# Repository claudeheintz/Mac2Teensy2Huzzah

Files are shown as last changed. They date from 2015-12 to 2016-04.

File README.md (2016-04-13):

# Mac2Teensy2Huzzah
This is a method for using a Teensy 2.0 or Teensy 2.0++ as a serial bridge so that an Adafruit Huzzah can be programmed from the Arduino IDE on Mac OS X 10.11.

First, load the Mac2Teensy2HuzzahSerialBridge sketch onto the Teensy.  Then, unplug the USB cable from the Mac and connect the Teensy and Huzzah as follows:

Connect V+ and Gnd as well as the serial RX/TX pins.  Note that the RX of the Teensy is connected to TX of the Huzzah and vice-versa.

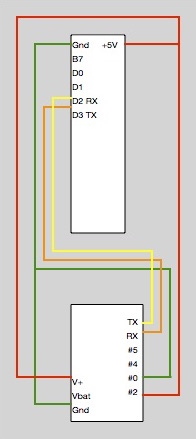
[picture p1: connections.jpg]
Connections


In addition, the Huzzah's GPIO0 pin should be connected to ground and the GPIO2 pin to +V in order to force the Huzzah into programming mode when it is powered on.  Here is the complete setup ready for the USB cable to be plugged into the Mac.

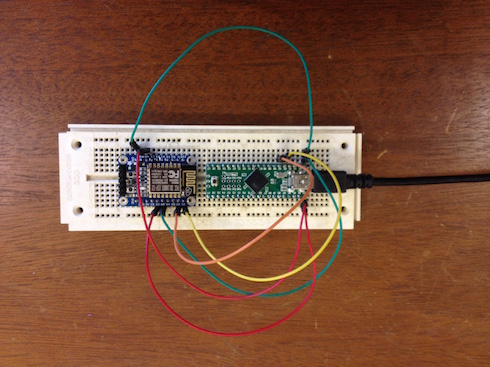
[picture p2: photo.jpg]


Full Step-by-Step:
* Load the Mac2Teensy2Huzzah.ino sketch onto the Teensy.
* Unplug the USB cable and connect the Teensy to the Huzzah as shown.
* Switch to your sketch that you want to load on the Huzzah
* Don't forget to change to Tools->Board: "Adafruit HUZZAH ESP8266".  The Teensy's serial port should still be selected in Tools->Port.
* Plug the USB cable into the Mac and click "Upload".
* After the sketch compiles, you should see the Teensy's LED light up as the program is uploaded to the Huzzah's flash.
* Once the upload is complete, be sure to disconnect GPIO0 from ground and GPIO2 from V+.

Eagle files are included for making a permanent programmer setup with a Teensy 2.0:

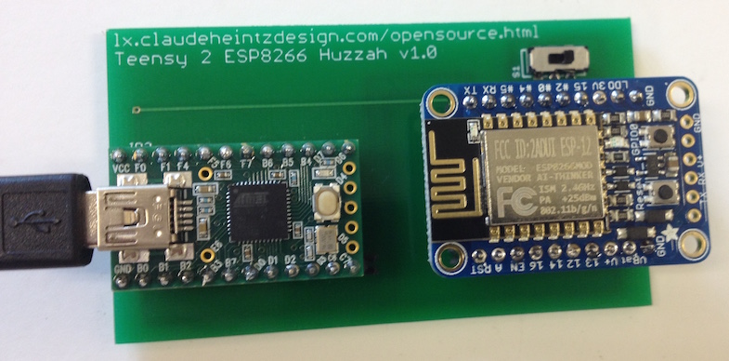
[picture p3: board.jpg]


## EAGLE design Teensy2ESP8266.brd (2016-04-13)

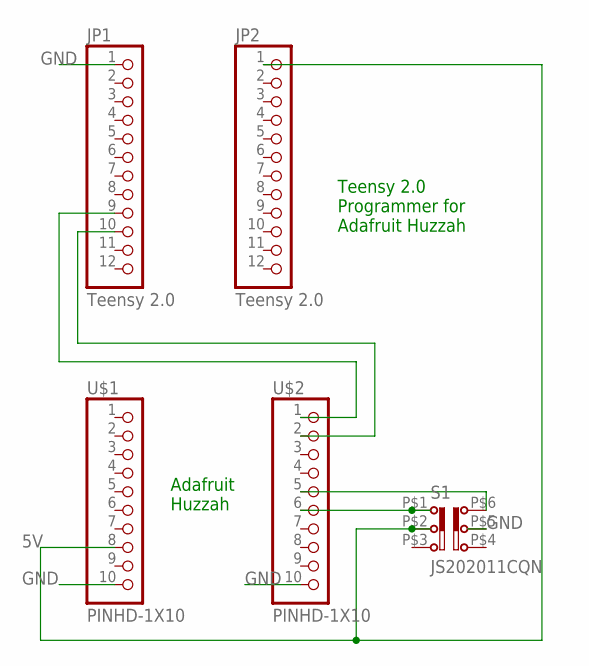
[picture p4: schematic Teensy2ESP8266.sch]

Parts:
JP1, JP2: Teensy 2.0; 1X12
S1: JS202011CQN
U$1, U$2: PINHD-1X10; 1X10-BIG

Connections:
5V: JP2.1, S1.P$2 (2), U$1.8
GND: JP1.1, S1.P$5 (5), U$1.10, U$2.10
unnamed: S1.P$1 (1), U$2.6
unnamed: S1.P$6 (4), U$2.5
RX2: JP1.9, U$2.1
TX2: JP1.10, U$2.2

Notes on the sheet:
Adafruit Huzzah
Teensy 2.0 Programmer for Adafruit Huzzah

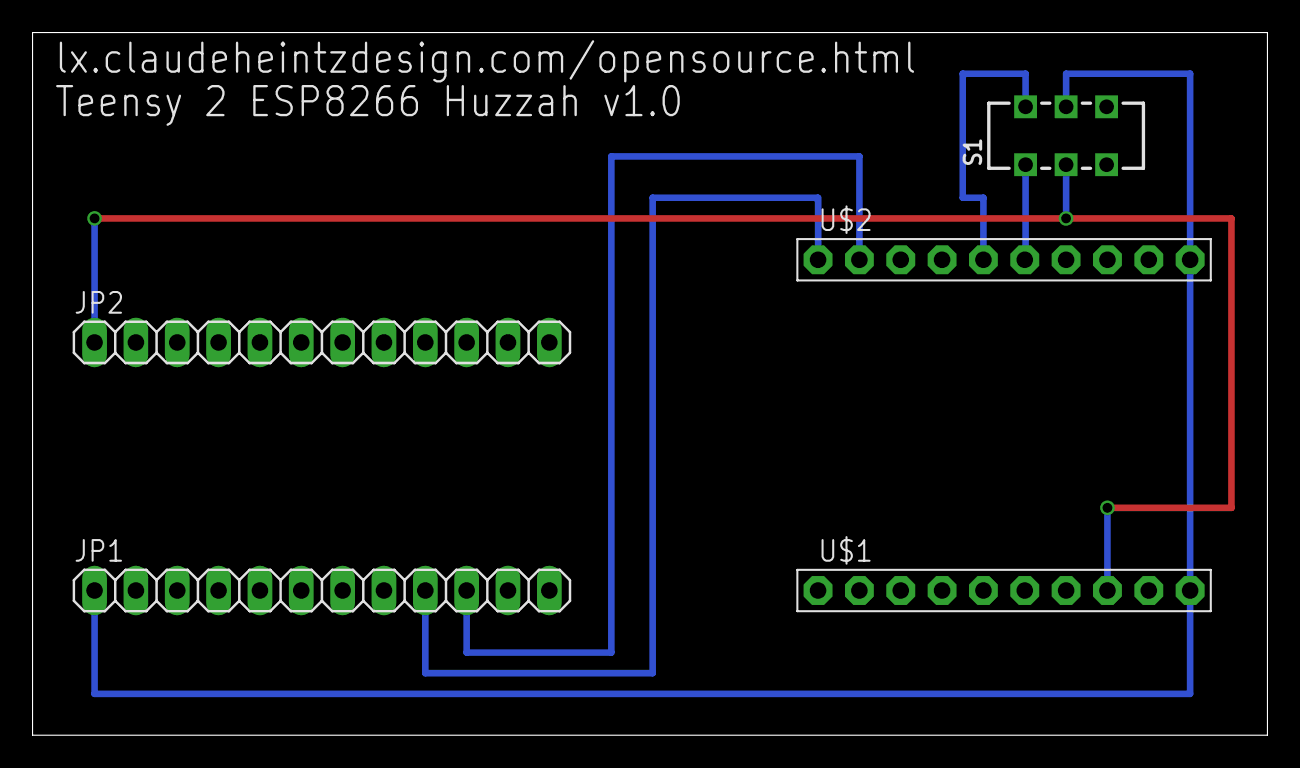
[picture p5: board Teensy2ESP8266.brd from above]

Board: 2 copper layers, 75.9 x 43.2 mm, 5 parts (0 on the bottom side), 6 nets.

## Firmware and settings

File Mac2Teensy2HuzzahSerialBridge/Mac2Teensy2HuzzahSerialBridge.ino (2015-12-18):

/* 
 *  Mac2Teensy2HuzzahSerialBridge
 *  by Claude Heintz 2015
 *
 *  This sketch allows a Teensy 2.0++ to be used as a serial
 *  connection between a Mac running OS X 10.11 and an
 *  Adafruit ESP8266 Huzzah so that a program can be uploaded
 *  from the Arduino IDE.
 *  
 *  The Teensy is connected to the Huzzah serial header using 4
 *  jumpers:
 *  
 *  Teensy GND to Huzzah serial header pin 1 (GND)
 *  Teensy +5v to Huzzah serial header pin 3 (Vcc)
 *  Teensy D2 (RX) to Huzzah serial header pin 5 (TX)
 *  Teensy D3 (TX) to Huzzah serial header pin 4 (RX)
 *  
 *  For uploading also make the following connections with jumpers:
 *      connect Huzzah GPIO2 to V+ 
 *      connect Huzzah GPIO0 to GND
 *      
 *  After making these connections on a breadboard, plug the Teensy
 *  into the Mac with a USB cable.  The Teensy will act as a serial
 *  bridge so that a program can be uploaded to the Huzzah.
 *  
 *  After flash upload is complete, disconnect
 *  the GPIO2 & GPIO0 jumpers.
 */

uint8_t abite;
int led = 6;	//built-in LED on Teensy 2.0++

void setup() {
  pinMode(led, OUTPUT);
  Serial.begin(115200);
  Serial1.begin(115200);
}

void loop() {
  if ( Serial.available() ) {
    abite = Serial.read();
    Serial1.write(abite);
    digitalWrite(led, HIGH);
  }
  if ( Serial1.available() ) {
    abite = Serial1.read();
    Serial.write(abite);
    digitalWrite(led, LOW);
  }
}

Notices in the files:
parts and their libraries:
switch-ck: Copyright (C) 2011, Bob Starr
